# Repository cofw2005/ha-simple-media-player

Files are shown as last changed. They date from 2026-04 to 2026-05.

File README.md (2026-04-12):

# Simple ESP32-S3 Media Player (ESPHome & PSRAM Optimized)

A high-performance, compact network audio player based on the ESP32-S3-DevkitC-1 and PCM5102A DAC. Optimized for **Music Assistant (Home Assistant)** with a focus on stability, zero-stutter playback, and deep software-hardware integration.

<div align="center">
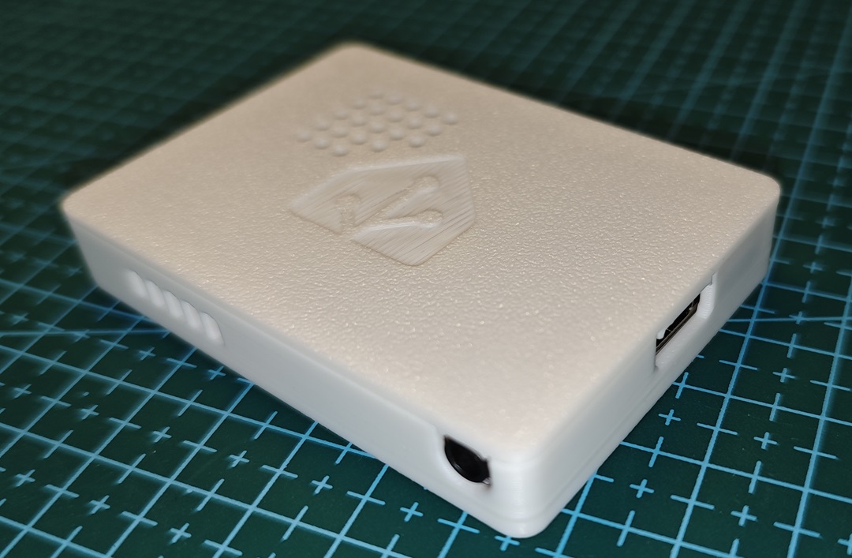
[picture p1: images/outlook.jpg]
  
</div>

<div align="center">
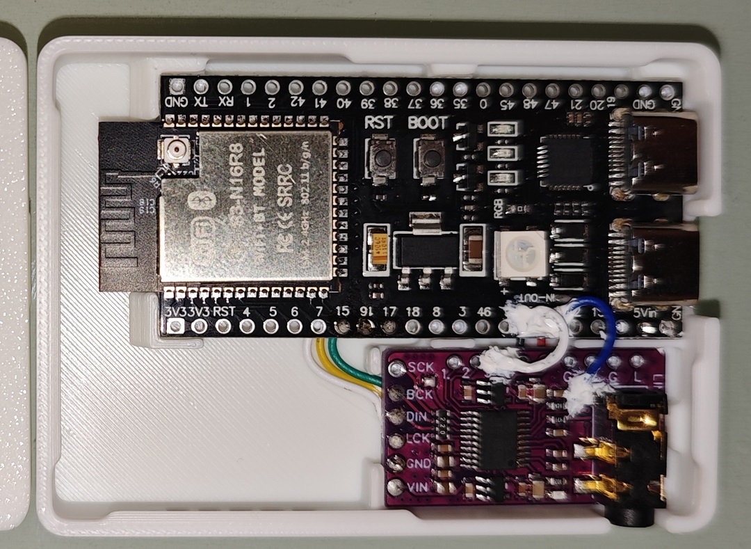
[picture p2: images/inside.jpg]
  
</div>

---

## 🚀 Key Features
* **Superior Stability:** Optimized for ESP32-S3 N16R8, utilizing specialized network buffers and PSRAM management to eliminate stuttering.
* **Hi-Fi Output:** Uses PCM5102A DAC with hardware-level pop-noise suppression and optimized I2S signaling.
* **Smart Power:** Integrated deep sleep logic with automatic headphone jack detection for energy efficiency.
* **Perfect Sync:** Full support for the Sendspin protocol, enabling low-latency multi-room audio synchronization.

---

## 📖 Project Structure
Detailed guides and technical insights are organized into the following sections:

* [🛠 **Hardware & Soldering Guide**](./docs/01.hardware_build.md) – Components, wiring diagrams, and assembly steps.
* [💻 **Software & Debugging Guide**](./docs/02.debugging.md) – YAML configuration, SDK optimizations, and performance tuning.
* [💡 **Notes & Tips**](./docs/03.notes_n_tips.md) – Critical debugging discoveries, hardware "gotchas," and optimization tricks.

---

## 📦 3D Enclosure Files
The enclosure is designed to be compact and functional. You can find the STL files in the `/stls` folder.

### Bottom Case Options:
* **Hidden Port:** Only exposes the UART port for a minimalist look.
* **Dual Port:** Both USB ports are accessible.

### Lid Options
* **Small Button (Black):** Features longer internal pillars to match the lower profile of black tactile switches (height of the swtich is about 2mm).
* **Large Button (White):** Features shorter pillars to accommodate the taller profile of white tactile switches (height of the swtich is about 3mm).
* **No-Button:** A clean, flat top for an enclosed aesthetic.

---

## 🤝 Acknowledgments
- **ESPHome Community**: For the powerful tools that make these projects possible.
- A huge thank you to [arhills](https://github.com/arhills) for his invaluable help and technical guidance throughout the development of this project.

---

## 📜 License

This project is licensed under the **GPL-3.0 License** - see the [LICENSE](LICENSE) file for details.

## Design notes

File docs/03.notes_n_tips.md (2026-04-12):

# 💡 Notes & Tips

_Detailed observations and technical solutions discovered during the development and debugging of the ESP32-S3 Media Player._

---

## 1. Pin Pull-up Workaround (Crucial)
During debugging, I found that setting `pullup: true` within the `deep_sleep` component didn't always take effect, leaving the pin in a floating state.
```
binary_sensor:
  - platform: gpio
    pin:
      number: GPIO11
      mode: INPUT_PULLUP # this PULLUP setting make it work
      allow_other_uses: true
    #use_interrupt: false
    name: "Plug Detection"
    id: plug_detection
deep_sleep:
  id: ds_config
  wakeup_pin:
    - pin:
        number: GPIO11
        # mode: INPUT_PULLUP --> the PULLUP setting here doesn't work
        allow_other_uses: true
      wakeup_pin_mode: IGNORE
```
* **Solution:** Re-declare the same pin as a `binary_sensor` and set the pull-up there. This forces the ESP32-S3 to correctly initialize the internal resistor.

## 2. Hardware "Gotchas"
* **DAC Silkscreen Error:** My PCM5102A board had inverted silkscreen labels for the H/L jumpers. Always verify continuity with a multimeter to confirm GND (L) before bridging pads.
* **Orientation:** Double-check the orientation of the wires relative to the board's front and back before soldering. It’s easy to mirror them by mistake.
* **Pin Conflict:** If using my enclosure design, **avoid using GPIO 3 and 8**, as these pins align with the internal support brackets. Additionally, **avoid GPIO 46**, as it is a strapping pin with specific hardware constraints.

## 3. Mute Control (XSMT) Simplification
In my initial build, I used a dedicated wire for software-based mute control. However, after extensive testing, I found the output quality of the PCM5102A to be excellent and free of significant pop noise. To simplify the build, I removed the control wire and used a solder bridge to permanently connect **XSMT (Pin 3)** to **High (H)**.

## 4. Network Performance vs. PSRAM Settings
I discovered an interesting relationship between the `network` and `psram` configuration flags in ESPHome. These settings significantly impact memory allocation and TCP window sizes:

* **Case A: High Performance Enabled**
  * **Settings:** `network: enable_high_performance: true` (or default) + `psram: ignore_not_found: false`.
  * **Log Snippet:**
    ```text
    INFO Applying high-performance lwip settings (PSRAM guaranteed): 512KB TCP windows, 512 mailbox sizes
    INFO Applying high-performance WiFi settings (PSRAM guaranteed): 512 RX buffers, 32 TX buffers
    ```
  * **Result:** This is the most aggressive setting for data throughput, requiring guaranteed PSRAM availability.

* **Case B: User Overridden (Partial)**
  * **Settings:** `network: enable_high_performance: false` + `psram: ignore_not_found: false`.
  * **Log Snippet:**
    ```text
    INFO High performance networking disabled by user configuration (overriding component request)
    INFO Applying high-performance WiFi settings (PSRAM guaranteed): 512 RX buffers, 32 TX buffers
    ```
  * **Result:** TCP buffers are restricted, but the WiFi driver still utilizes high-performance RX buffers because PSRAM is guaranteed.

* **Case C: Optimized/Conservative Mode**
  * **Settings:** `network: enable_high_performance: false` + `psram: ignore_not_found: true` (or default).
  * **Log Snippet:**
    ```text
    INFO Applying optimized lwip settings: 65KB TCP windows, 64 mailbox sizes
    INFO Applying optimized WiFi settings: 64 RX buffers, 64 TX buffers
    ```
  * **Result:** ESPHome scales down to conservative "Optimized" settings, significantly reducing memory footprint.

**Technical Discovery:** The `enable_high_performance` flag primarily affects the LwIP (TCP/IP stack) send/receive windows, whereas the "PSRAM guaranteed" status (controlled by `ignore_not_found: false`) is the prerequisite for the system to scale up the WiFi driver's internal RX/TX buffers.

## 5. Pipeline Format Priority
An unusual behavior was observed when both `announcement_pipeline` and `media_pipeline` are defined. If the audio formats (e.g., MP3 vs. FLAC) differ between the two pipelines, Home Assistant or Music Assistant defaults to the format defined in the **announcement pipeline**, even when streaming regular media. To ensure consistency and avoid unexpected transcoding, it is recommended to keep the format settings identical across both pipelines.

---
**Back to Home:** [README.md](../README.md)

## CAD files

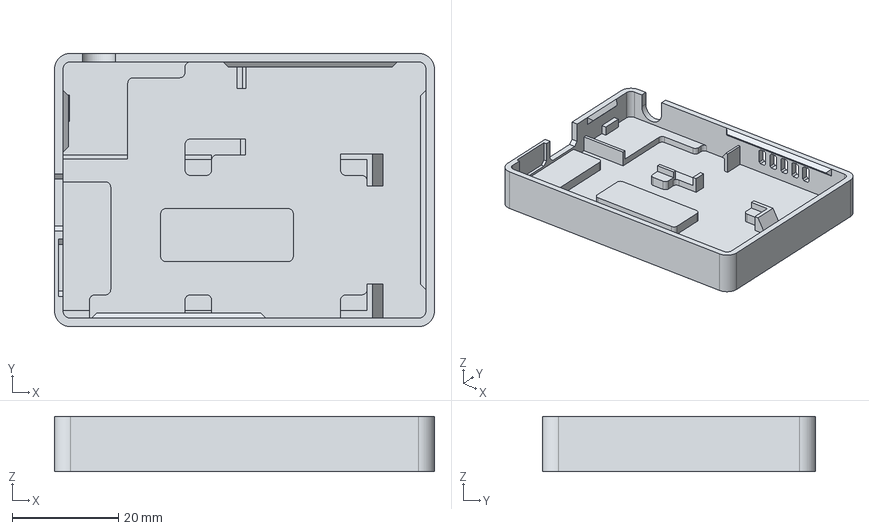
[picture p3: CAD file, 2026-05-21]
stls/simple_case-one_port.step
71.6 x 51.5 x 10.4 mm

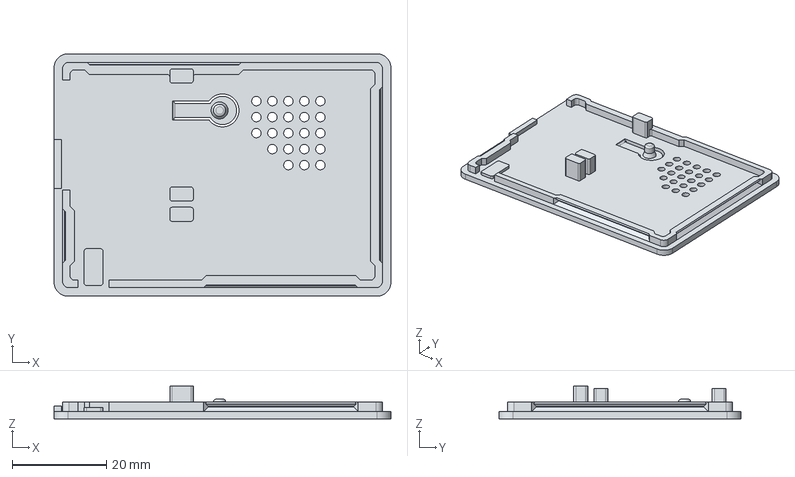
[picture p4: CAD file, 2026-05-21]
stls/simple_case_cover-small_button.step
71.6 x 51.5 x 7.00 mm

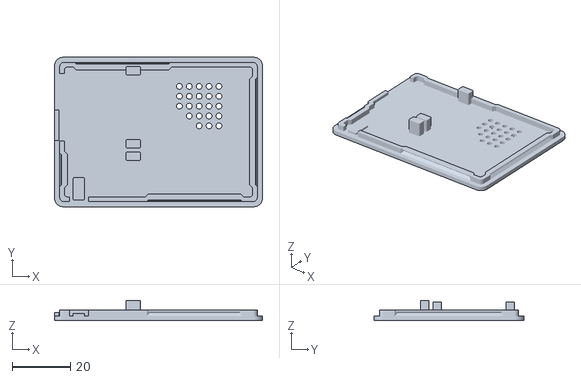
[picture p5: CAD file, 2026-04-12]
stls/simple_case_cover-no_button.stl
71.6 x 51.5 x 7.00

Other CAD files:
stls/simple_case-two_ports.stl
stls/simple_case_cover-big_button.stl
stls/simple_case-one_port.stl
stls/simple_case_cover-small_button.stl

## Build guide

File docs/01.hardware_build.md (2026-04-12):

# Building & Soldering Guide

_This section covers the hardware preparation and soldering process for the ESP32-S3 Media Player._

---

## Step 1: PCB Preparation

Before wiring, prepare the two boards (ESP32-S3 and PCM5102A DAC) by configuring their solder bridges.

<div align="center">
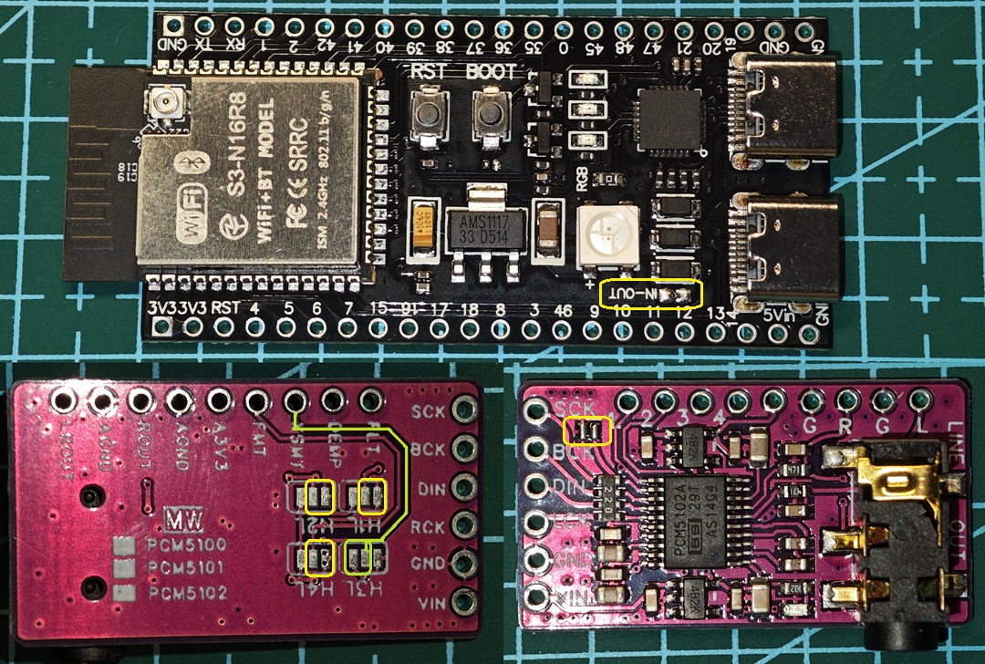
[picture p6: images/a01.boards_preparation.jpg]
  
</div>

### ESP32-S3 Board
* Connect the **IN-OUT pads** using a solder bridge to enable 5V power output to external devices.
* **Note on Voltage:** Some online guides suggest using 3.3V to power the DAC. In my testing, there was no significant difference in audio quality. Using 5V results in a cleaner wire layout, which is what I chose for this build. You may decide based on your preference.

### PCM5102A DAC Board
* **Backside Jumper Settings:** Bridge the center pads of **1, 2, and 4** to **L (GND)**.
* **Mute Control (Jumper 3):** * If you don't need manual mute control: Bridge the center pad to **H**.
    * If you want software/manual control: Leave it open.
    * **⚠️ Important Tip (Silkscreen Error):** On my specific DAC board, the silkscreen was printed incorrectly. I initially bridged to "L," but a multimeter check revealed that the side labeled "H" was actually the true GND. **Always measure continuity with a multimeter or trace the PCB paths before soldering to confirm which side is GND.**
* **Frontside:** Connect the **SCK and GND** pads with a solder bridge.

## Step 2: Cable Preparation

I2S is a high-frequency signal; keeping wires short is critical for signal integrity.

<div align="center">
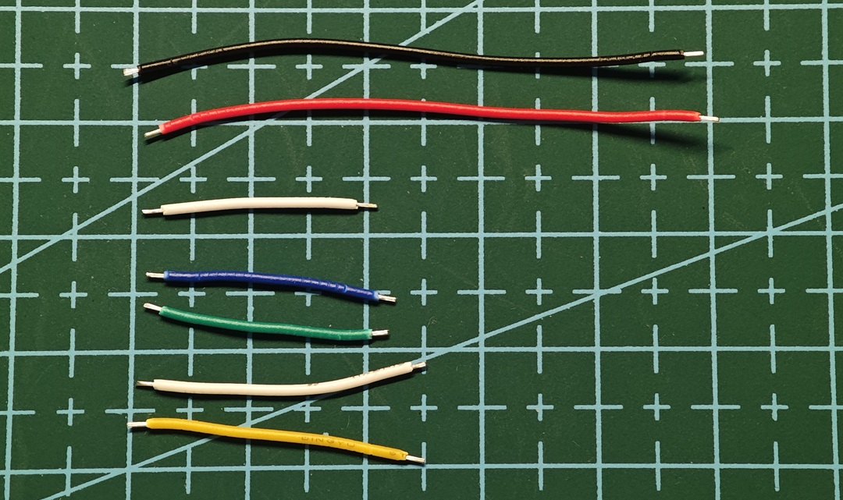
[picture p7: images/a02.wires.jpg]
  
</div>

* **I2S Signal Wires:** Suggested length 20mm ~ 30mm. I used one 20mm and two 25mm wires. This length is optimized for the custom enclosure.
* **Power & Ground:** Approximately 50mm (VCC wire can be shorter if using 3.3V).
* **Control Wires:** Two 20mm wires (one for the **XSMT** mute pin and one for **Jack Detection**).
* **Note:** Short wires lead to a cleaner build but require more precision during soldering. Longer wires are acceptable if you need more room to maneuver.

## Step 3: Soldering the Connections

Map and solder the wires according to the schematic.

<div align="center">
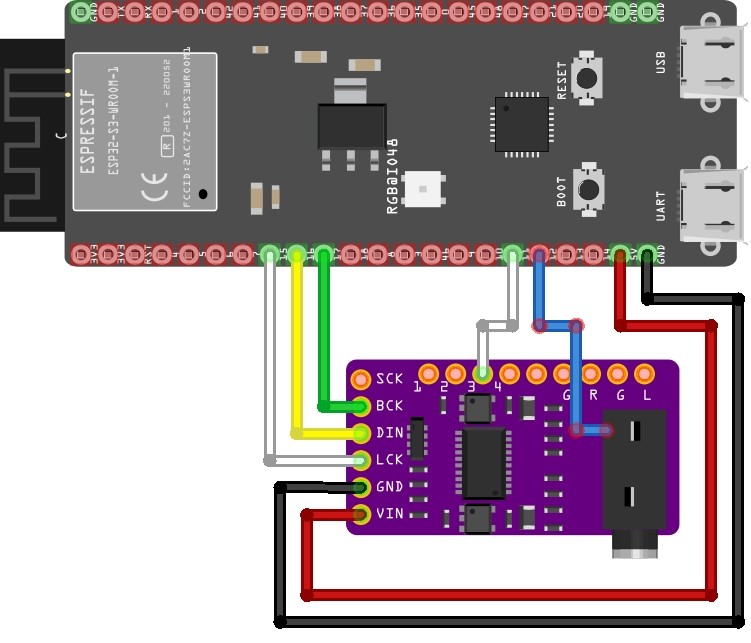
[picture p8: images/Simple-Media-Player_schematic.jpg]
  
</div>

* **I2S Pins:** While pins 4, 5, 6, 7, 15, 16, and 17 on the ESP32-S3 are all fine for use as I2S signal wires, I used **GPIO 15, 16, and 17** for the shortest physical path.
* **Control Pins:** GPIO **10** for XSMT (Mute) and GPIO **11** for Headphone Detection. (Optional)
* **Routing:** For a professional look inside the enclosure, I routed the I2S and power lines along the **back** of the board, while the mute and detection lines run across the **top**.
* **⚠️ Fitment Tip:** If you choose 3.3V power, use the **second 3.3V pin** on the ESP32 board. Using the first one will interfere with the enclosure's support brackets, preventing the board from seating correctly.

<div align="center">
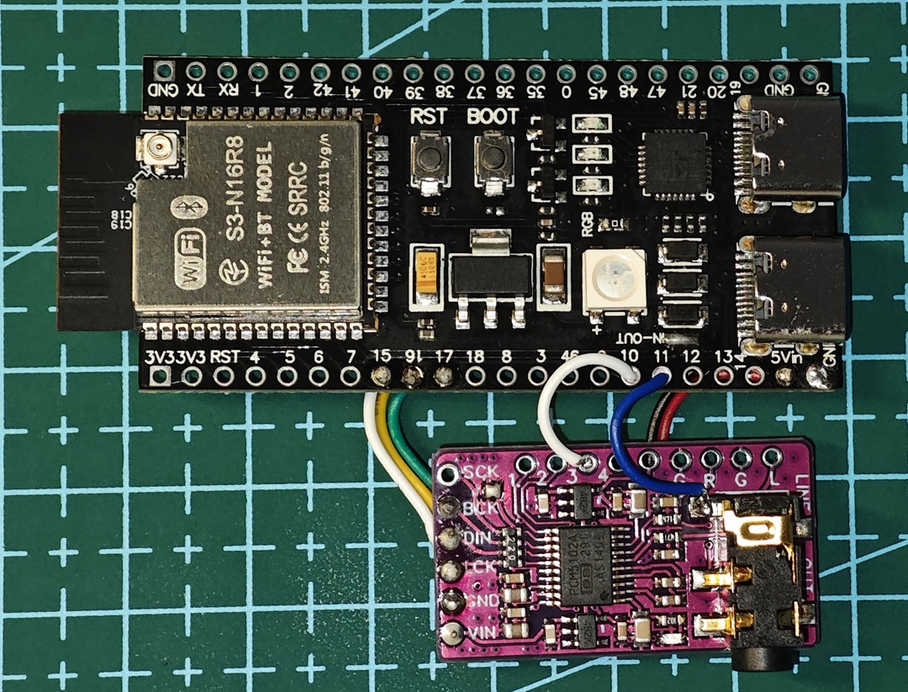
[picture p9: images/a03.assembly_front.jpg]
  
</div>

<div align="center">
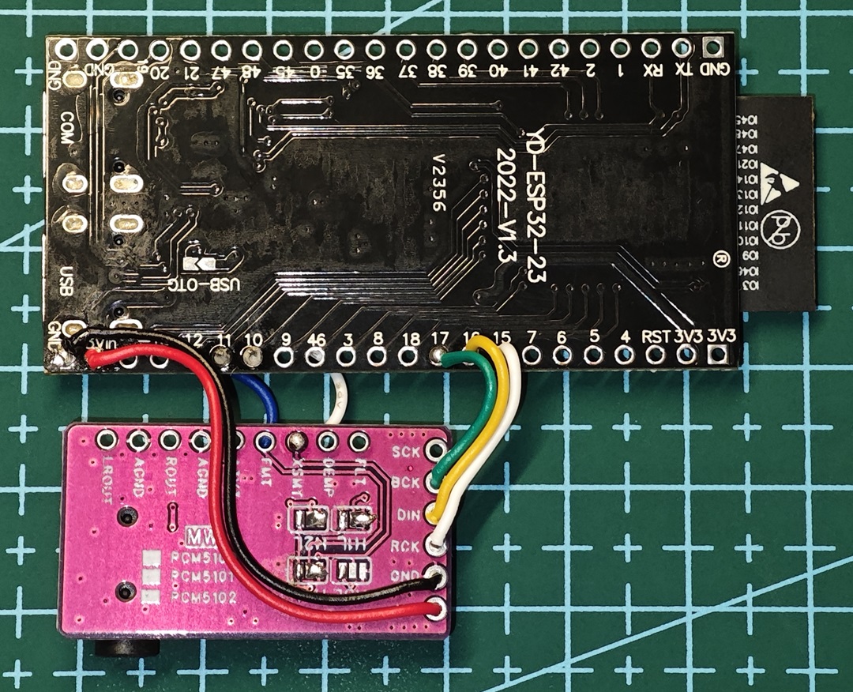
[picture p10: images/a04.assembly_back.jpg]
  
</div>

## Step 4: Final Assembly

1.  **Stress Relief:** Apply a small amount of glue (like 704 glue) at the base of the wires to provide strain relief.
2.  **Mounting:** Once the glue is dry, place the boards into the enclosure. Route the backside wires through the gaps between the support blocks.
3.  **Done!** Your hardware is now ready for the software.

<div align="center">
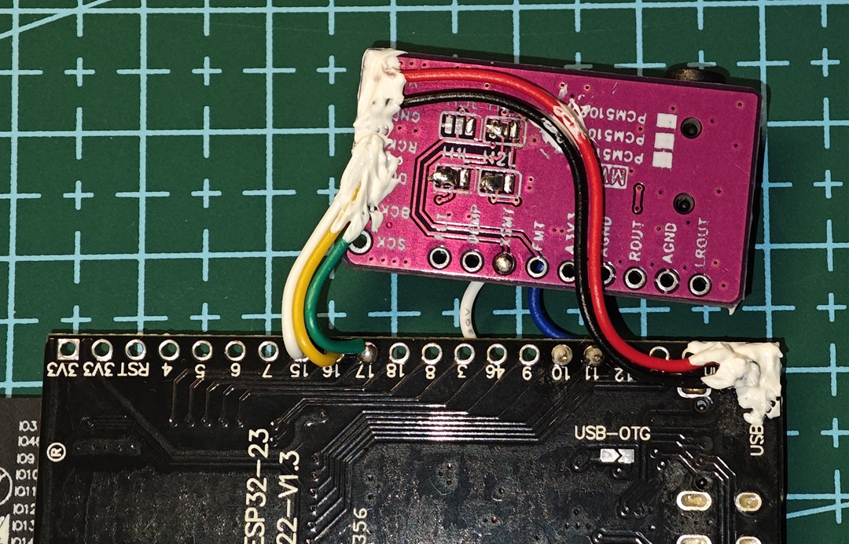
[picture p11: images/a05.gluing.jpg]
  
</div>

<div align="center">
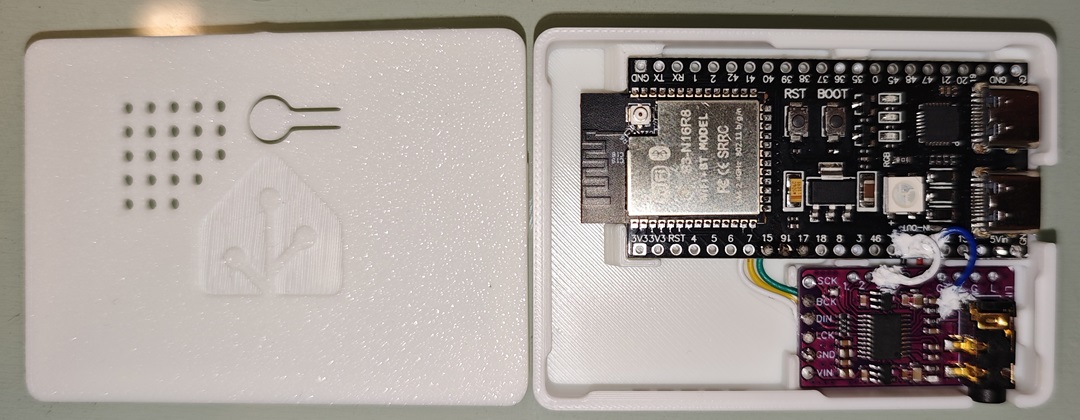
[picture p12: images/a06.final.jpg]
  
</div>

---
**Next Step:** [Software Configuration & Debugging](./02.debugging.md)

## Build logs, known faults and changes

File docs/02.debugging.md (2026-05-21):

# Software Configuration & Debugging

There are many code snippets shared online, but I found that most of them didn't work for my specific setup. After several nights of troubleshooting, I identified the root causes and finalized a configuration that works perfectly for my hardware. 

**Note:** Hardware varies from person to person. What works for others might not work for you. Please use the following as a reference and adjust based on your specific needs.

---

## 1. The Key Solution: Network Performance Mode
First thing first, the most critical discovery for my hardware was the `network: enable_high_performance: false` setting. 

In recent ESPHome versions, this is often enabled by default when using media player components. However, I constantly encountered "decoding" and "ring buffer" errors. On my device, the "High Performance" mode consumed excessive SRAM, leaving insufficient space for the audio ring buffer, which caused stuttering or total decoder failure.

**By explicitly setting `enable_high_performance: false`, my media player finally began to play smoothly.**

---

## 2. 🛠Implementation Approaches & Debugging
During development, I experimented with three distinct software architectures to find the best balance between audio stability, feature set, and resource management.

> [!IMPORTANT]
> ### 📢 Important Update: `external_components` Now Native
> 
> * **What Changed:** The `external_components` (including the custom audio pipelines, `media_source`, and `sendspin`) used in this guide have now been **officially integrated into core ESPHome**. 
> * **Action Required:** You can now safely remove the entire `external_components:` block from your YAML files.
> * **Note:** This streamlined native setup has **not been fully tested** by me yet. If you run into any compilation or playback issues, please drop a log in the **Issues** section, and we will figure it out together!

---

### 1. Standard Dual-Channel Speaker Architecture
This approach uses the standard ESPHome `Speaker Audio Media Player` components configured for dual-channel output.

* **Performance Observations:**
    Despite extensive `sdkconfig` optimizations for SRAM/PSRAM and various `buffer_duration` adjustments, I could not achieve 100% stutter-free playback for **FLAC** files; occasional stutter persisted. However, **MP3** playback was flawlessly stable.
* **Optimal Configuration:** See [`speaker_audio_media_player.yaml`](../yamls/speaker_audio_media_player.yaml).
* **Usage Notes:**
    * **Integration:** Must be added to Home Assistant (HA) via the ESPHome integration first.
    * **Music Assistant (MA) Setup:** To use this in MA, navigate to *Settings -> Player Providers -> Home Assistant MediaPlayers* and manually add the entity.

### 2. Sendspin-Optimized Speaker Source
This is a "lean" configuration designed specifically for the `Sendspin` protocol, utilizing a single `media_source`. I removed the `mixer` component and retained only one `resampler` for a more direct pipeline.

* **Performance Observations:**
    Interestingly, this configuration uses **more PSRAM** than the dual-channel approach but **reduces SRAM overhead**. Crucially, **FLAC playback was completely smooth** with no stuttering issues.
* **Optimal Configuration:** See [`simple_sendspin_media_player.yaml`](../yamls/simple_sendspin_media_player.yaml).
* **Usage Notes:**
    * **MA Native Support:** MA recognizes `Sendspin` as a native protocol, which is more robust than the standard HA player integration. MA will auto-discover the player upon boot.
    * **Entity Behavior:** This setup does *not* create a `media_player` entity directly under the HA ESPHome device (sensors remain normal). You can, however, sync it back to HA as a media player entity through MA settings.
    * **Optimization Tip:** MA defaults to a **48,000Hz** sampling rate for Sendspin. Setting your ESPHome `sample_rate` to `48000` bypasses the need for the `resampler` speaker, saving CPU cycles.

### 3. Hybrid Pipeline (Voice-PE Style)
Inspired by the `home-assistant-voice-pe` configuration, this setup uses `external_components` (custom `http_request`, `media_source`, and `sendspin`) to build separate **Announcement** and **Media** pipelines.

* **Performance Observations:**
    This is the most feature-rich version, allowing the player to act as a native Sendspin device in MA while simultaneously exposing a `media_player` entity to HA for TTS and notifications. Similar to the first approach, **FLAC** files occasionally struggled with bandwidth/buffer issues, so **MP3** remains the recommended format for total reliability.
* **Optimal Configuration:** See [`speaker_source_sendspins_media_player.yaml`](../yamls/speaker_source_sendspins_media_player.yaml).

### 💡 Summary Comparison Table

| Feature | Standard Dual-Channel | Sendspin Only | Hybrid Pipeline |
| :--- | :--- | :--- | :--- |
| **FLAC Stability** | Fair (Occasional Stutter) | **Excellent** | Fair (Occasional Stutter) |
| **MP3 Stability** | Excellent | Excellent | Excellent |
| **HA Entity** | Native | Via Music Assistant | Native |
| **MA Protocol** | HA Proxy | **Native Sendspin** | **Native Sendspin** |
| **Best Use Case** | General HA usage | Dedicated High-Fi Music | Advanced Home Automation |

---

## 3. Configuration Breakdown
Here are some specific parts of my code that you may want to understand or adapt:

### PlatformIO & PSRAM Support
The default `esp32-s3-devkitc-1` board definition in ESPHome does not include PSRAM support. To ensure the **N16R8** module is correctly recognized with its 8MB Octal PSRAM, I explicitly declared the `platformio_options`. This is essential for the board to utilize the extended memory.

```
  platformio_options: 
    board_build.f_flash: 80000000L
    board_build.f_cpu: 240000000L
    board_build.flash_mode: qio
    board_build.psram_type: opi
    board_build.arduino.memory_type: qio_opi
    board_upload.maximum_size: 16777216
    board_upload.speed: 921600
    build_flags: 
      - -DBOARD_HAS_PSRAM
```

### SDKConfig Optimizations
Under the `esp32` section, I applied several `sdkconfig_options` to free up as much SRAM as possible (e.g., disabling Bluetooth). 
* **Disclaimer:** I am still exploring the full impact of some of these settings. Please use them with caution.

```
    sdkconfig_options:
      CONFIG_BT_ENABLED: "n"
      CONFIG_ESP_WIFI_TASK_CORE_ID: "0"
      # Configs to improve data cache, these configs consume about 65KB SRAM
      CONFIG_ESP32S3_DATA_CACHE_64KB: "y"
      CONFIG_ESP32S3_DATA_CACHE_LINE_64B: "y"
      CONFIG_ESP32S3_INSTRUCTION_CACHE_32KB: "y"
      # Configs to optimize PSRAM usage
      CONFIG_SPIRAM_RODATA: "y"
      CONFIG_SPIRAM_FETCH_INSTRUCTIONS: "y"
      CONFIG_SPIRAM_TRY_ALLOCATE_WIFI_LWIP: "y"
      CONFIG_SPIRAM_ALLOW_BSS_SEG_EXTERNAL_MEMORY: "y"
      CONFIG_MBEDTLS_EXTERNAL_MEM_ALLOC: "y"
```

### Add-on Packages (Addons)
The content in the `packages` section (like `monitor_memory.yaml`) does not affect the core functionality. You can add or remove these as needed:
* **Deep Sleep:** I implemented a feature that triggers deep sleep when the headphone jack detection pin is high (no plug inserted). If you didn't solder the detection wire, remove this package.
* **Sensors & Monitoring:** The sensors included in the YAML are for debugging purposes to monitor SRAM and PSRAM usage in real-time. You can remove them once your setup is stable.

---
**Next Step:** Choose the YAML that fits your needs and refer to the [Notes & Tips](./03.notes_n_tips.md) for deep-level optimizations.

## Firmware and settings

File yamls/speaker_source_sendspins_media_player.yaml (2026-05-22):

# =============================================================================
# HARDWARE INFORMATION
# =============================================================================
# ESP32 Chip: ESP32-S3 rev0.2, 2 core(s)
# ESP32-S3-DevkitC-1 V1.0
# Onboard LED -> GPIO48
# =============================================================================

# Define the device name and friendly name
substitutions:
  name: "esp32-media-player"
  friendly_name: "ESP32 Media Player"
  led_gpio_pin: GPIO48
  sample_rate: 48000

# =============================================================================
# Basic ESPHome configurations
# =============================================================================
# Core board ESP32-S3-DevkitC-1
# Lgger, OTA, Fallback hotpot and PSRAM enabled
# By default of PlatformIO, board: esp32-s3-devkitc-1 means for a non-PSRAM version.
# "platformio_options" must be defined to overwrite the default options of the board,
# to give right confirmation for N16R8
# =============================================================================

esphome:
  name: $name
  friendly_name: $friendly_name
  platformio_options: 
    board_build.f_flash: 80000000L
    board_build.f_cpu: 240000000L
    board_build.flash_mode: qio
    board_build.psram_type: opi
    board_build.arduino.memory_type: qio_opi
    board_upload.maximum_size: 16777216
    board_upload.speed: 921600
    build_flags: 
      - -DBOARD_HAS_PSRAM

# According to latest ESPHome documentation, variant is recommended practice,
# board option is added for backwards compatibility, it might be removed later
# Use the ESP32 Platform configuration cpu_frequency, flash_size to define right parameter for N16R8
# Disable bluetooth as it is not used in the components
# Add some SRAM and PSRAM improvements
esp32:
  variant: esp32s3
  board: esp32-s3-devkitc-1
  cpu_frequency: 240MHz
  flash_size: 16MB
  framework:
    type: esp-idf
    version: recommended
    sdkconfig_options:
      CONFIG_BT_ENABLED: "n"
      CONFIG_ESP_WIFI_TASK_CORE_ID: "0"
      # Configs to improve data cache, these configs consume about 65KB SRAM
      CONFIG_ESP32S3_DATA_CACHE_64KB: "y"
      CONFIG_ESP32S3_DATA_CACHE_LINE_64B: "y"
      CONFIG_ESP32S3_INSTRUCTION_CACHE_32KB: "y"
      # Configs to optimize PSRAM usage
      CONFIG_SPIRAM_RODATA: "y"
      CONFIG_SPIRAM_FETCH_INSTRUCTIONS: "y"
      CONFIG_SPIRAM_TRY_ALLOCATE_WIFI_LWIP: "y"
      CONFIG_SPIRAM_ALLOW_BSS_SEG_EXTERNAL_MEMORY: "y"
      CONFIG_MBEDTLS_EXTERNAL_MEM_ALLOC: "y"

# Enable logging
logger:
  level: DEBUG
  logs:
    sensor: WARN 

# Wifi setup
wifi:
  ssid: !secret wifi_ssid
  password: !secret wifi_password
  
  output_power: 8.5dB
  power_save_mode: NONE

network:
  enable_high_performance: false

# Enable PSRAM (Typically on ESP32-S3 modules, a 2MB PSRAM will use quad mode,
# while 8 or 16MB will use octal mode)
psram:
  mode: octal
  speed: 80MHz
  ignore_not_found: false

# Enable Home Assistant API
api:
  encryption:
    key: !secret api_key

  reboot_timeout: 0s

# Enable http request
http_request:
  buffer_size_rx: 4096

# =============================================================================
# Media player / I2S configurations
# =============================================================================
# At sample rate 44100Hz, 2 channels, 16bit, every 1ms buffer uses about 176.4 Bytes
# 100ms - 17.64K, 200ms - 35.2KB, 500ms - 86.13KB
# If no sound by setting bits_per_sample to 32bit, set to 16bit instead
# =============================================================================
i2s_audio:
  - id: i2s_out
    i2s_lrclk_pin: GPIO15
    i2s_bclk_pin: GPIO17

speaker:
  - platform: i2s_audio
    id: i2s_audio_speaker
    i2s_audio_id: i2s_out
    sample_rate: $sample_rate
    i2s_dout_pin: GPIO16
    bits_per_sample: 16bit
    dac_type: external
    channel: stereo
    timeout: never
    buffer_duration: 100ms

  - platform: mixer
    id: mixer_speaker_id
    output_speaker: i2s_audio_speaker
    source_speakers:
      - id: media_spk_mixer_input
        buffer_duration: 100ms
        timeout: never
      - id: announcement_spk_mixer_input
        buffer_duration: 100ms
        timeout: never
    num_channels: 2
    task_stack_in_psram: true

  - platform: resampler
    id: media_resampling_speaker
    output_speaker: media_spk_mixer_input
    sample_rate: $sample_rate
    bits_per_sample: 16
    buffer_duration: 100ms
    task_stack_in_psram: true
  - platform: resampler
    id: announcement_resampling_speaker
    output_speaker: announcement_spk_mixer_input
    sample_rate: $sample_rate
    bits_per_sample: 16
    buffer_duration: 100ms
    task_stack_in_psram: true

sendspin:
  id: sendspin_hub
  task_stack_in_psram: false

media_source:
  - platform: http_request
    id: http_announcement_source
    buffer_size: 250000
  - platform: http_request
    id: http_media_source
    buffer_size: 500000
  - platform: sendspin
    id: sendspin_media_source
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

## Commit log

2026-04-12 initial version
    [simple_case-one_port.stl, simple_case-two_ports.stl, simple_case_cover-big_button.stl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]
2026-04-12 Minor text improvements
    Added workaround for pull-up issue in deep sleep configuration and clarified DAC silkscreen error. Updated notes on pipeline format priority behavior.
2026-05-21 Upload two Step files.
    [simple_case-one_port.step, simple_case_cover-small_button.step]
